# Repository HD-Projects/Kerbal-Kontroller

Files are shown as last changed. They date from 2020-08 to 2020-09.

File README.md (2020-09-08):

# Kerbal Kontroller




This is a external controller for the game Kerbal Space Program you need a [Artemis ATP](https://www.sparkfun.com/products/15442), [Artemis Module](https://www.sparkfun.com/products/15484), or any other board with 30+ digital pins.

# Table of Contents

* [Design](#design)
* [Software](#software)
* [Built it yourself](#Built-it-yourself)
* [Files](#File-system)

# Design

## Chosing which pins to include

After a little research on past designs for a kerbal controller we found that we wanted one that was bigger and used more high quality switches. After some frequency research(Playing KSP) we found that you pressed these buttons

* Throttle Up
* Cut Throttle
* Fine Throttle Control(Dial or Slide Potentiometer)
* Action groups
* WASD + Roll
* SAS Options
* Stage
* Quick Save
* Revert Buttons
* Manuver buttons
* Time Warp

We looked at this list and thought that it would be to many pins(~45) to implement on one arduino or RPi and we narrowed it down to this list

* Stage
* Throttle Dial
* WASD + Roll
* Action Groups(6)
* Internal Action groups
* SAS, RCS, Modable switch
* Quick Save, Revert save
* 4 Mod buttons

These buttons and switches took up about 25 pins so they could fit easly on one arduino so we moved on to designing the layout of the board. 

## Designing the layout

### First design

For our fist design we wanted to have a big board 30cm wide and 20cm tall, it was going to be huge! We kept adding on to this design and ended up with this design in this design we added 5 modable buttons for different buttons on the keyboard that the end user could change.

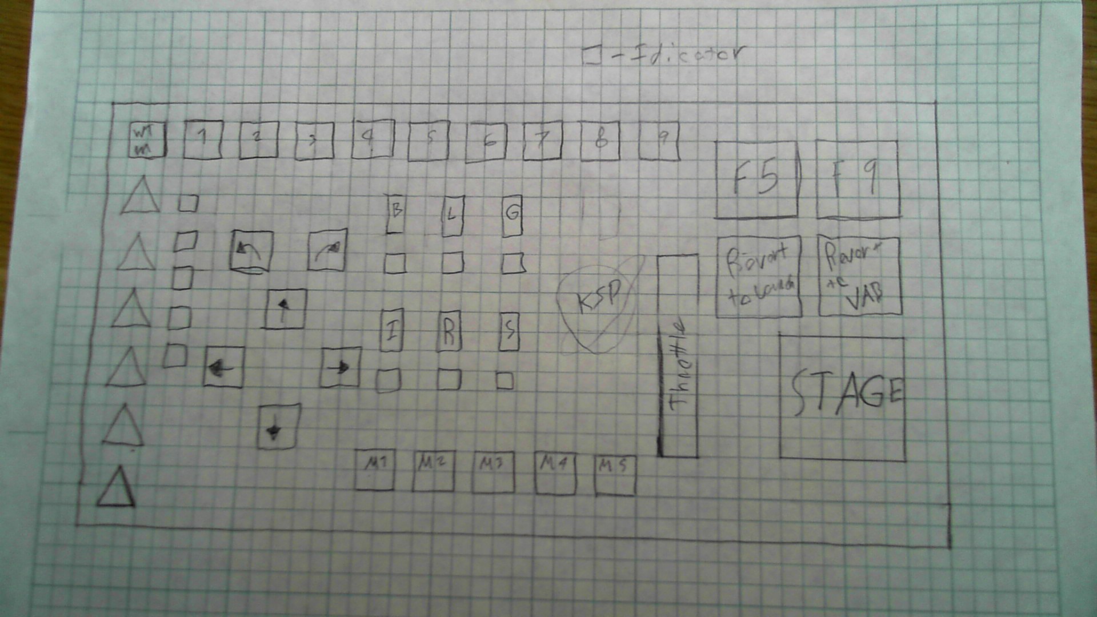
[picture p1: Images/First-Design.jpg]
First Design


We worked on thsi design for a while and created 2 prototypes in [this folder](Design/v.1) or [this folder](Design/v.2) We found that this design was going to be way too big and changed over to our much smaller second design 

### Second and Final Design

On our second design we got rid of the huge time warp selector, although helpful used up too many pins and could be a lot smaller. for this design we designed the layout of the buttons and switches then chose the size of the plexiglass we wanted

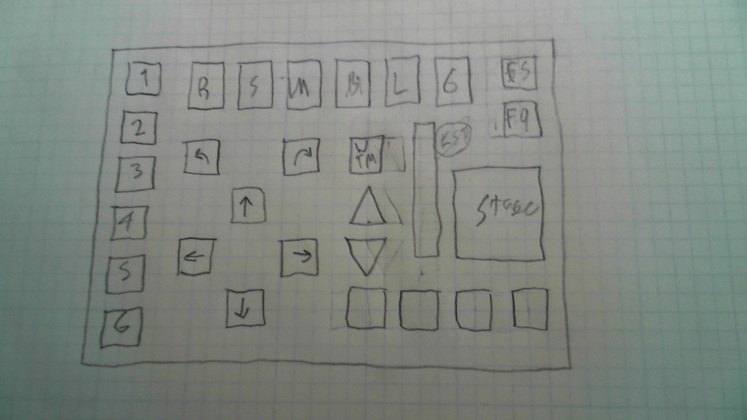
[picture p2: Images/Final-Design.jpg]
Final Design


This was a much smaller form factor and only have 22 buttons, 6 switches and one analog gauge, for a total of 28 digital pins, and only on analog pins. 

After we finnished the design we wanted to have a to scale model. we wanted some costomizablity for a flat design or a proped up design this is our first prototype of a proped up design

Front

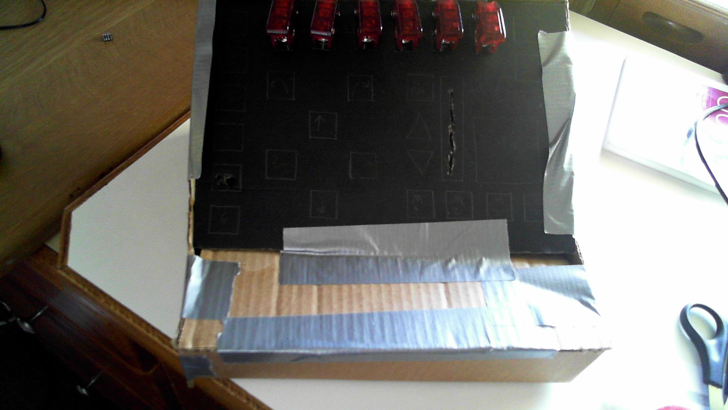
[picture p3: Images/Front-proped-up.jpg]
Proped up


Side

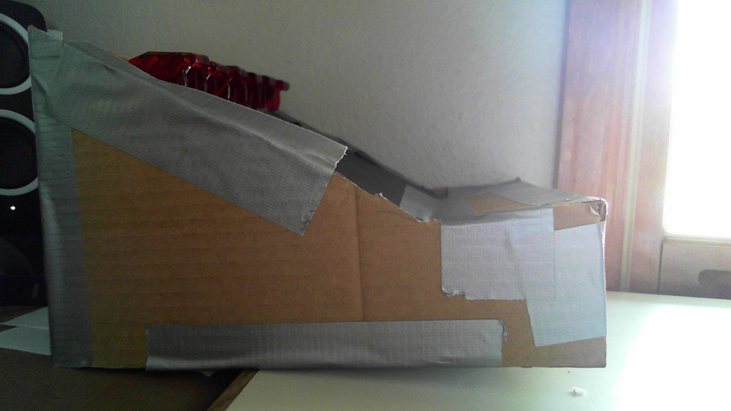
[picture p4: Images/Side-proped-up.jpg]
Proped up


Proped up

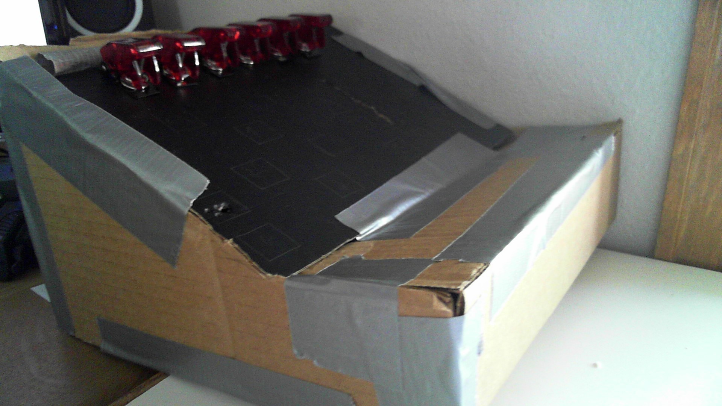
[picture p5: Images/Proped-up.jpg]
Proped up


We found that this would be the perfect size for our kerbal controller.

# Software

After doing some research on KSP mods for kerbal controllers we found this [post](https://www.reddit.com/r/KerbalControllers/comments/ajavos/software_comparison_thread/) on the different ways to do it can after looing at the pros and cons of each of them we thought that Kerbal Simpit would be the best for cosntomizablity and ease of use.

# Build-it-yourself

# Approach 1
Look at our [website](https://hdprojects.dev/ksp/diy)

# Approach 2

* First consult the parts list to buy all the parts

* Then get the faceplate cut and the keycaps 3d printed

* slot the keys+keycaps into ther respictive slots along with all the other parts

* use wire and solder all the parts into the right  i/o pins (digital pins for everything)

* download our code onto your aurdino

* profit?

# File-system

### CAD Section (design folder)

This is split into three parts 

* v.1
    * v.1 was our first design for our kerbal controller.
* v.2
    * v.2 was the same design just we totally redid the CAD Model to fix the many errors we had before.
* Final 
    * This is the only totally finnished design that would acctually work if you tried it.
   
### Glowforge (parts folder)

* glowforge folder (holds stl files)

* alternative folder (holds alternatives to using your own glowforge)

# 3d printing (in design folder) 
    
  * stl files
  
  * alternative folder (holds alternatives to using your own printer)

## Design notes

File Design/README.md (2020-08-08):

# design.md 

This folder holds all the cad files for the various iterations of the design, v1 is the initial release, v2 is the second release and "final" is the CAD files for the final design 
all the code files and parts are designed for the final version but we kept the last two in there if you want inspiration.

Look in the images folder for hot renders of the controller (so that those 41 hrs of cpu time aren't wasted).

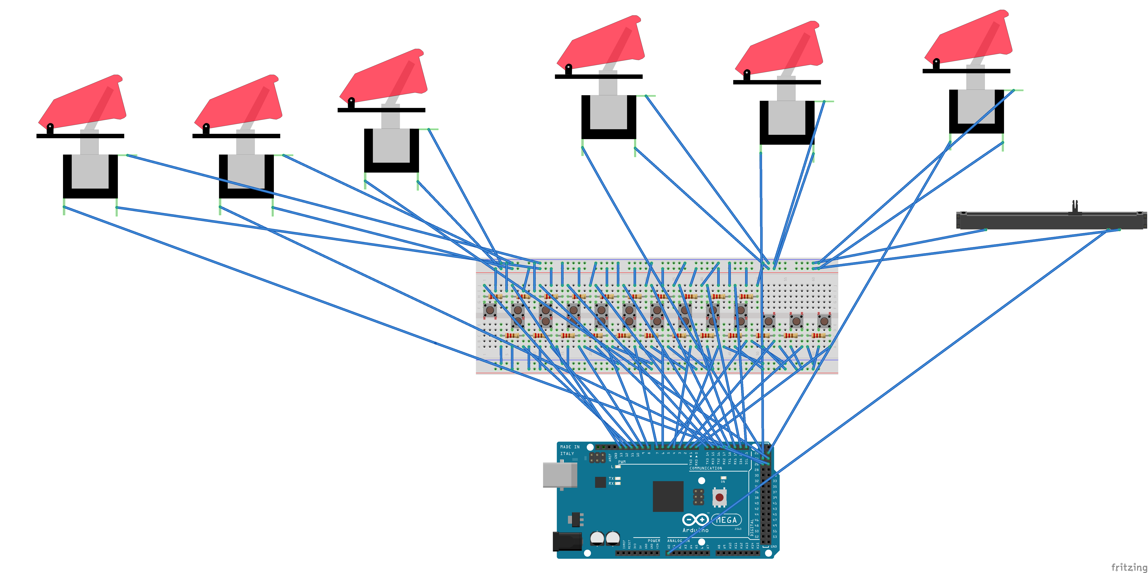
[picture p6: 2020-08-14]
Design/Final/Fritzing/Final_bb.png

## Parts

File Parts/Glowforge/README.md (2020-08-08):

# Glowforge

The 'final' folder  holds the info you need to use a glowforge or similar laser cutter to cut your controller parts. The SVG file is the file that will control the cut of the faceplate. If you would like to modify the faceplate open the SVG in a program such as Inkscape and edit it until satisfactory.

# Alternative 1

Use a laser cutting service that does the laser cutting for you

   Upload the SVG file from the "final" folder to a website such as https://www.ponoko.com/designs (our recommended laser cutting site) and select a material. Next proceed to    checkout and wait for your custom made faceplate to arrive. Note, do nout use a material such as steel or aluminum if you don't have a drill that can cut mounting holes in such a material.

# Alternative 2

Find a makerspace near you and get your item cut

   Open a website such as https://makerspaces.make.co/ to find a local makerspace near you. Then look at the makerspaces website (for our example https://members.10bitworks.com/) to see if they have a laser cutter capable of cutting your plexi. If they do follow the instructions for getting to use the equitpment and once you have secured a time to use the machine upload the svg from the final folder and proceed to get your faceplate cut/engraved.

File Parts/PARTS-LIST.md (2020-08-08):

# Parts list

## Table of Contents

* [3D Printing Files](#3D-Printing)
* [Electronic Parts](#Electronics)
* [Glowforge Files](#Glowforge)
* [Other Hardware](#Hardware)

## 3D-Printing

* [9 Keys(3d-printing option)](3d-Print/9-keys.stl) or buy 22 keycaps (18.57) from [3dhubs](https://www.3dhubs.com/) or (20.90) at [sparkfun](https://www.sparkfun.com/products/15305)

* [Stage](3d-Print/Stage.stl)  (8.80) from [3dhubs](https://www.3dhubs.com/)

## Electronics

* [Artemis Board W/ 28+ Digital Pins](https://www.sparkfun.com/search/results?term=artemis) (24.95)
* [22 Cherry MX keys](https://novelkeys.xyz/collections/switches/products/cherry-switches)  (21)
* [Slide Potentiometer](https://www.sparkfun.com/products/9119) & [Knob](https://www.sparkfun.com/products/9120) (2.95) + (0.95)
* [Toggle Switch and Cover](https://www.sparkfun.com/products/11310) (17.70)
* [Some Hookup Wire](https://www.sparkfun.com/products/8024) (2.50)
* [Resistors](https://www.sparkfun.com/products/14490) (0.95)

## Glowforge

* [Front Plexi](Glowforge/front-plexi.svg)

## Hardware

* [Plywood 1/4 in(1 Sheet)](https://www.homedepot.com/p/Sanded-Plywood-Common-15-32-in-x-2-ft-x-2-ft-Actual-0-451-in-x-23-75-in-x-23-75-in-300888/202093832) (7.98)
* [Plexiglass 1/16"](https://www.amazon.com/transparente-policarbonato-resistente-plexigl%C3%A1s-manualidades/dp/B07MQTDF4R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) (9.99)

Total Price

(18.57)keycaps + (8.80)stage btn + (24.95)aurdino + (21)keys + (2.95)slide pot + (0.95)slide pot knob + (17.70)toggle switch + (2.50)wire + (0.95)resistor + (7.98)plywood + (9.99)plexi = **115.89** for a completed controller

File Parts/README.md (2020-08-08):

# Parts

These are all the parts and files needed to complete the build.

# [PARTS-LIST.md](PARTS-LIST.md)

This is a file holding info on every part necessary to complete the build. It has links to buy components and links to the necessary files for the components you make yourself.

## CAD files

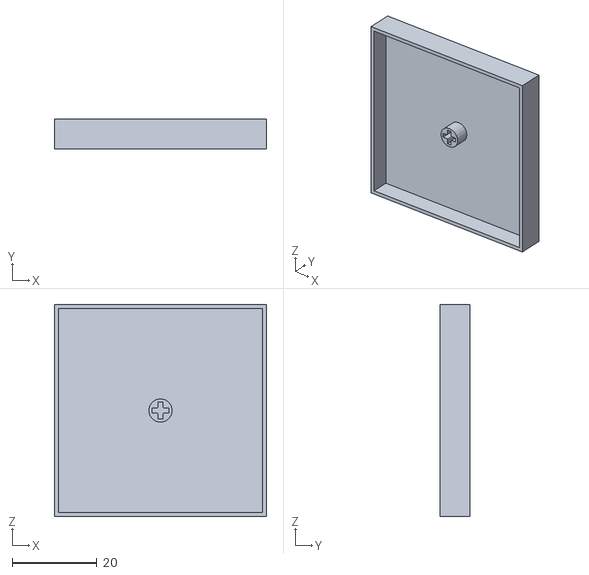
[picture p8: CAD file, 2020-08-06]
Design/Final/Inventor/Parts/Stage Keycap.obj
50.0 x 7.00 x 50.0

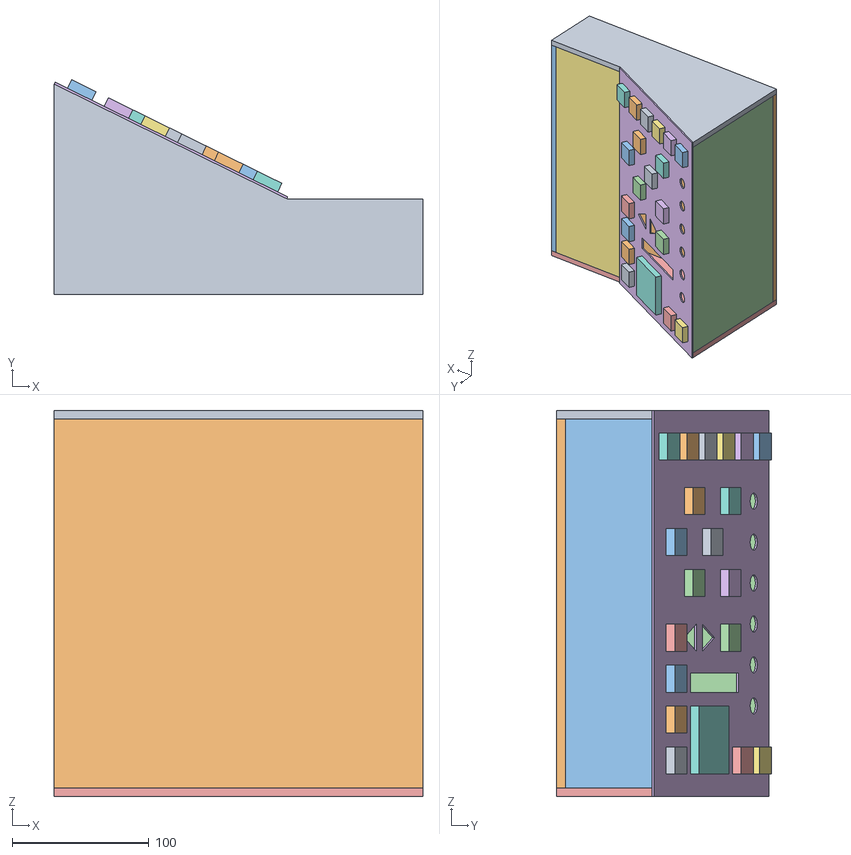
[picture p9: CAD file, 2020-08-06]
Design/Final/Object/Final.obj
270.0 x 157.3 x 282.7

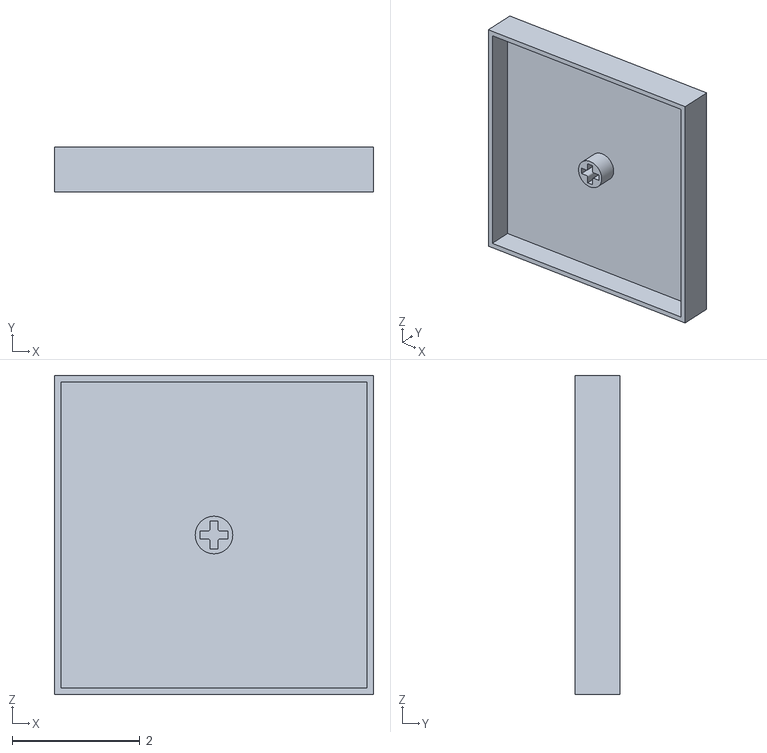
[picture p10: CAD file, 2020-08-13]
Parts/3d-Print/Stage.stl
5.00 x 0.7 x 5.00

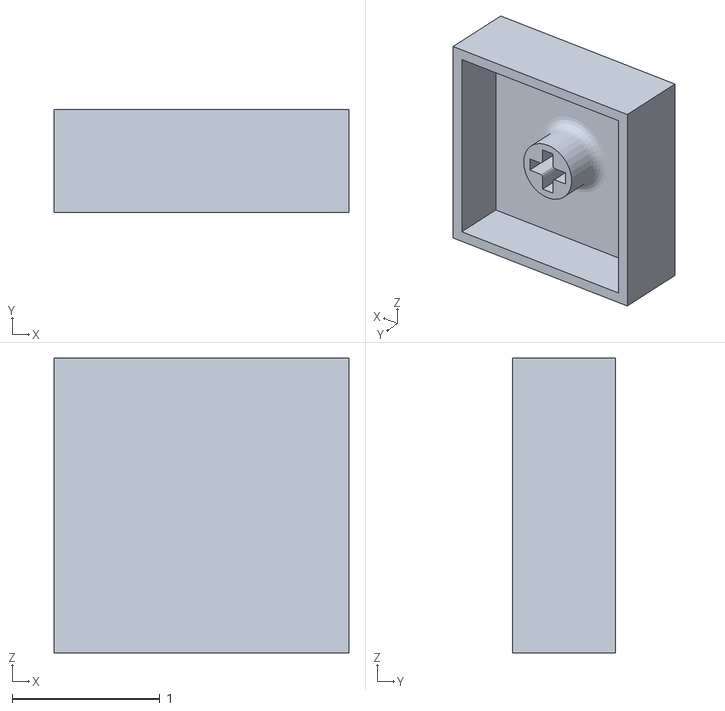
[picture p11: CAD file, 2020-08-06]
Parts/3d-Print/Keycap.stl
2.00 x 0.7 x 2.00

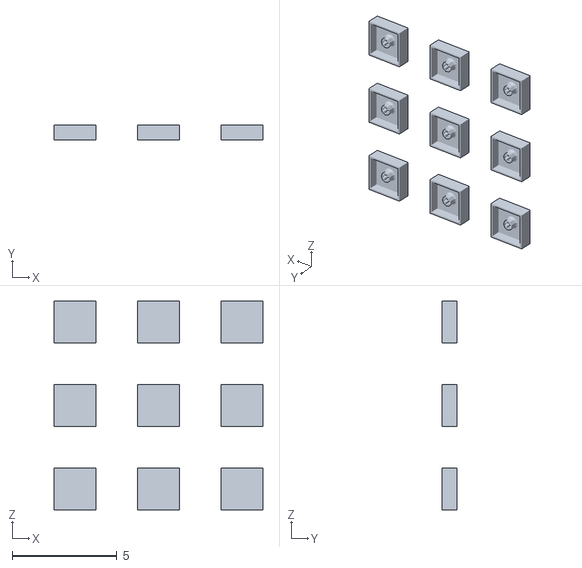
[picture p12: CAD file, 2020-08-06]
Parts/3d-Print/9-keys.stl
10.00 x 0.7 x 10.0

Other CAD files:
Design/Final/Step/Final.stp
Design/Final/Inventor/Final.iam
Design/Final/Inventor/OldVersions/Final.0010.iam
Design/Final/Inventor/OldVersions/Front Plywood.0001.ipt
Design/Final/Inventor/OldVersions/Front.0001.ipt
Design/Final/Inventor/OldVersions/v.3.0006.iam
Design/Final/Inventor/Parts/Arm Rest.ipt
Design/Final/Inventor/Parts/Back.ipt
Design/Final/Inventor/Parts/Bottom.ipt
Design/Final/Inventor/Parts/Front Plexi cutout.ipt
Design/Final/Inventor/Parts/Front.ipt
Design/Final/Inventor/Parts/Keycaps.ipt
Design/Final/Inventor/Parts/OldVersions/Arm Rest.0001.ipt
Design/Final/Inventor/Parts/OldVersions/Back.0002.ipt
Design/Final/Inventor/Parts/OldVersions/Bottom.0001.ipt
Design/Final/Inventor/Parts/OldVersions/Front Plexi cutout.0005.ipt
Design/Final/Inventor/Parts/OldVersions/Front Plywood.0004.ipt
Design/Final/Inventor/Parts/OldVersions/Front.0002.ipt
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

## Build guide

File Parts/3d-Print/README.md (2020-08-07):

# 3D-Printing Option

The 3d printing option prints all the keycaps on the board in squares. There are 2 STL Files you need to print the [Stage Button](Stage.stl) and the other [Keycaps](Keycap.stl) but we made a 100 mm x 100 mm [9 Keycap option](9-keys.stl)

# Alternative 1 

Use a custom 3d printing service

Use a website such as https://www.3dhubs.com/ https://www.shapeways.com/ https://i.materialise.com/en where you upload an stl file and get it printed and shipped to you. These parts will cost 10-15$ to make so you might consider using alternative 2 if you want to save money

# Alternative 2

find a makerspace near you and get your item printed

   Open a website such as https://makerspaces.make.co/ to find a local makerspace near you. Then look at the makerspaces website (for our example https://members.10bitworks.com/) to see if they have a 3d printer avaliabe for use. If they do follow the instructions for getting to use the equitpment and once you have secured a time to use the machine upload the stl from the 3d-print folder and proceed to get your parts printed.

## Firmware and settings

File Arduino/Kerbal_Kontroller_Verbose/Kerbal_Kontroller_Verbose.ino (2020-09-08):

// FILE: Kerbal_Kontroller_Verbose.ino

#include "KerbalSimpit.h"
#include "KerbalSimpitMessageTypes.h"
#include "PayloadStructs.h"

// Defining limits

//Dead Zone

#define DEADZONE 200

// Throttle

#define THROTTLE_HIGH -32768
#define THROTTLE_LOW 0

// Rotation Messages

#define ROTATION_HIGH 32767
#define ROTATION_LOW -32768

// Translation Messages

#define TRANSLATION_HIGH 32767
#define TRANSLATION_LOW -32768

// Kerbal Simpit rotation message

rotationMessage rotationMsg;

/*

Const switch setup we recomend the following
settings if you are following our directions

*/

// SAS + RCS + Mod

#define SAS_switch 6
#define RCS_switch 7 // The-Bit-One(Or u/hogthardwarf) will never have this switch on
#define mod_switch 8

// Built in Action Groups

#define lights_switch 9
#define brakes_switch 10
#define gear_switch 11

/*

Const for button pin, we reccomend the
following settings but feel free to change
it for your controller

*/

#define stage_button 2

// Controls

#define roll_right_button 12
#define roll_left_button 13
#define pitch_left_button 14
#define pitch_right_button 15
#define yaw_up_button 16
#define yaw_down_button 17

// Warp button

#define WTM_button 2 // Warp to manuver
#define warp_up_button 2
#define warp_down_button 2

// Quick Saves

#define quick_save_button 2
#define revert_quick_save_button 2


// Action Groups

#define action_1_button 0
#define action_2_button 1
#define action_3_button 2
#define action_4_button 3
#define action_5_button 4
#define action_6_button 5

// Mod Buttons

#define mod_1_button 18
#define mod_2_button 19
#define mod_3_button 20
#define mod_4_button 21

/*

Analog Pins

*/

// Throttle

#define throttle_gauge A5

// Done Setting Up Pins

KerbalSimpit mySimpit(Serial);

// My Simpit init

void simpitSetup(int pin) {
    Serial.begin(115200);

    digitalWrite(pin, HIGH);

    // This loop continually attempts to handshake with the plugin.
    // It will keep retrying until it gets a successful handshake.
    while (!mySimpit.init()) {
        delay(100);
    }
    // Turn off the built-in LED to indicate handshaking is complete.
    digitalWrite(pin, LOW);
}

void setup() {
    pinMode(LED_BUILTIN, OUTPUT);

    simpitSetup(LED_BUILTIN);

    // Start input setup

    // SAS + RCS + Mod

    pinMode(SAS_switch, INPUT);
    pinMode(RCS_switch, INPUT);
    pinMode(mod_switch, INPUT);

    // Built-in Action groups

    pinMode(lights_switch, INPUT);
    pinMode(brakes_switch, INPUT);
    pinMode(gear_switch, INPUT);

    // Stage

    pinMode(stage_button, INPUT);

    // Controls

    pinMode(roll_right_button, INPUT);
    pinMode(roll_left_button, INPUT);
    pinMode(pitch_left_button, INPUT);
    pinMode(pitch_right_button, INPUT);
    pinMode(yaw_up_button, INPUT);
    pinMode(yaw_down_button, INPUT);

    // Warp Buttons

    pinMode(WTM_button, INPUT);
    pinMode(warp_up_button, INPUT);
    pinMode(warp_down_button, INPUT);

    // Quick Saves

    pinMode(quick_save_button, INPUT);
    pinMode(revert_quick_save_button, INPUT);

    // Action Groups

    pinMode(action_1_button, INPUT);
    pinMode(action_2_button, INPUT);
    pinMode(action_3_button, INPUT);
    pinMode(action_4_button, INPUT);
    pinMode(action_5_button, INPUT);
    pinMode(action_6_button, INPUT);
}

void loop() {
    mySimpit.update();

    // Debounce

    // Stage
    if(digitalRead(stage_button) == HIGH){
        // Delay 50 for hardware Debounce

        delay(50);
        
        if(digitalRead(stage_button) == LOW){
            // Button Press Counted

            mySimpit.activateAction(STAGE_ACTION);
        }
    }

    // IDK if Kerbal Simpit supports Warping yet

    if(digitalRead(WTM_button) == HIGH){
        // Delay 50 for hardware Debounce

        delay(50);
        
        if(digitalRead(WTM_button) == LOW){
            // Button Press Counted

            // IDK
        }
    } 

    // Time warp up

    if(digitalRead(warp_up_button) == HIGH){
        // Delay 50 for hardware Debounce

        delay(50);
        
        if(digitalRead(warp_up_button) == LOW){
            // Button Press Counted

            // press(".")  no timewarp on Artemis ATP
        }
    } 

    // Time warp down

    if(digitalRead(warp_down_button) == HIGH){
        // Delay 50 for hardware Debounce

        delay(50);
        
        if(digitalRead(warp_down_button) == LOW){
            // Button Press Counted

            // press(",")  no timewarp on Artemis ATP
        }
    } 

    // Press button to quick save

    if(digitalRead(quick_save_button) == HIGH){
        // Delay 50 for hardware Debounce

        delay(50);
        
        if(digitalRead(quick_save_button) == LOW){
            // Button Press Counted

            // press(F5)  no timewarp on Artemis ATP
        }
    }

    // Press button to revert

    if(digitalRead(revert_quick_save_button) == HIGH){
        // Delay 50 for hardware Debounce

        delay(50);
        
        if(digitalRead(revert_quick_save_button) == LOW){
            // Button Press Counted

            // press(F9) & hold no timewarp on Artemis ATP
        }
    }

    // Action group 1

    if(digitalRead(action_1_button) == HIGH){
        // Delay 50 for hardware Debounce

        delay(50);
        
        if(digitalRead(action_1_button) == LOW){
            // Button Press Counted

            mySimpit.toggleCAG(1);
        }
    }

    // Action group 2

    if(digitalRead(action_2_button) == HIGH){
        // Delay 50 for hardware Debounce

        delay(50);
        
        if(digitalRead(action_2_button) == LOW){
            // Button Press Counted

            mySimpit.toggleCAG(2);
        }
    }

    // Action group 3

    if(digitalRead(action_3_button) == HIGH){
        // Delay 50 for hardware Debounce

        delay(50);
        
        if(digitalRead(action_3_button) == LOW){
            // Button Press Counted

            mySimpit.toggleCAG(3);
        }
    }

    // Action group 4

    if(digitalRead(action_4_button) == HIGH){
        // Delay 50 for hardware Debounce

        delay(50);
        
        if(digitalRead(action_4_button) == LOW){
            // Button Press Counted

            mySimpit.toggleCAG(4);
        }
    }

    // Action group 5

    if(digitalRead(action_5_button) == HIGH){
        // Delay 50 for hardware Debounce

        delay(50);
        
        if(digitalRead(action_5_button) == LOW){
            // Button Press Counted

            mySimpit.toggleCAG(5);
        }
    }

    // Action group 6

    if(digitalRead(action_6_button) == HIGH){
        // Delay 50 for hardware Debounce

        delay(50);
        
        if(digitalRead(action_6_button) == LOW){
            // Button Press Counted

            mySimpit.toggleCAG(6);
        }
    }

    /* 

    Mod buttons

    The mod buttons have 2 choices debounce or constaint
    like the control buttons the below code is the debounce
    put a close tag below, customize the action and brake the close tag
    
    

    // Mod 1

    if(digitalRead(mod_1_button) == HIGH){
        // Delay 50 for hardware Debounce

        delay(50);
        
        if(digitalRead(mod_1_button) == LOW){
            // Button Press Counted

            // Your Action
        }
    }

    // Mod 1

    if(digitalRead(mod_2_button) == HIGH){
        // Delay 50 for hardware Debounce

        delay(50);
        
        if(digitalRead(mod_2_button) == LOW){
            // Button Press Counted

            // Your Action
        }
    }

    // Mod 3

    if(digitalRead(mod_3_button) == HIGH){
        // Delay 50 for hardware Debounce

        delay(50);
        
        if(digitalRead(mod_3_button) == LOW){
            // Button Press Counted

            // Your Action
        }
    }

    // Mod 1

    if(digitalRead(mod_4_button) == HIGH){
        // Delay 50 for hardware Debounce

        delay(50);
        
        if(digitalRead(mod_4_button) == LOW){
            // Button Press Counted

            // Your Action
        }
    }

    */

    /*

    Second option

    Press down for cuntinuous action

    

    // Mod 1

    if(digitalRead(mod_1_button)){
        // Your Action
    }

    // Mod 2

    if(digitalRead(mod_2_button)){
        // Your Action
    }

    // Mod 3

    if(digitalRead(mod_3_button)){
        // Your Action
    }

    // Mod 4

    if(digitalRead(mod_4_button)){
        // Your Action
    }

    */

    // Set up rotation masking to know what to send

    rotationMsg.mask = 1|2|4;

    // Set roll

    if(digitalRead(roll_right_button)){
        // Set rotaion message roll
        rotationMsg.roll = 32767;
    }
    if(digitalRead(roll_left_button)){
        // Set rotaion message roll
        rotationMsg.roll = -32768;
    }

    // Set pitch

    if(digitalRead(pitch_left_button)){
        // Set rotaion message pitch
        rotationMsg.pitch = 32767;
    }
    if(digitalRead(pitch_right_button)){
        // Set rotaion message pitch
        rotationMsg.pitch = -32768;
    }

    // Set yaw

    if(digitalRead(yaw_up_button)){
        // Set rotaion message yaw
        rotationMsg.pitch = 32767;
    }
    if(digitalRead(yaw_down_button)){
        // Set rotaion message yaw
        rotationMsg.pitch = -32768;
    }

    // Send rotationMsg to the Kerbal Simpit plugin
    mySimpit.send(ROTATION_MESSAGE, rotationMsg);

    int brakesDigitalRead = digitalRead(gear_switch); // 1 Getting status of brakes switch we are using an integer variable but only two values are 
    // possible "HIGH" meaning true or activate and and "LOW" meaning false
    int lightDigitialRead = digitalRead(lights_switch); // 2
    int gearDigitalRead = digitalRead(gear_switch); // 3
    int sasDigitalRead = digitalRead(SAS_switch); // 4
    int rcsDigitalRead = digitalRead(RCS_switch); // 5
    int modDigitalRead = digitalRead(mod_switch); // 6

    if (brakesDigitalRead == HIGH /* high is this case is erqual to a boolean 'true' */) {
        mySimpit.deactivateAction(BRAKES_ACTION); // deavtivating brakes
    }
    else /* checking if button is not active or "LOW" */ {
        mySimpit.activateAction(BRAKES_ACTION);  // activating brakes
    }
    if (lightDigitialRead == HIGH /* high is this case is erqual to a boolean 'true' */) {
        mySimpit.deactivateAction(LIGHT_ACTION); // deavtivating brakes
    }
    else /* checking if button is not active or "LOW" */ {
        mySimpit.activateAction(LIGHT_ACTION);  // activating brakes
    }
    if (gearDigitalRead == HIGH /* high is this case is erqual to a boolean 'true' */) {
        mySimpit.deactivateAction(GEAR_ACTION); // deavtivating brakes
    }
    else /* checking if button is not active or "LOW" */ {
        mySimpit.activateAction(GEAR_ACTION);  // activating brakes
    }

    if (sasDigitalRead == HIGH /* high is this case is erqual to a boolean 'true' */) {
        mySimpit.deactivateAction(SAS_ACTION); // deavtivating brakes
    }
    else /* checking if button is not active or "LOW" */ {
        mySimpit.activateAction(SAS_ACTION);  // activating brakes
    }

    if (rcsDigitalRead == HIGH /* high is this case is erqual to a boolean 'true' */) {
        mySimpit.deactivateAction(RCS_ACTION); // deavtivating brakes
    }
    else /* checking if button is not active or "LOW" */ {
        mySimpit.activateAction(RCS_ACTION);  // activating brakes
    }

    //!!!!!!!!!!!!!!!!
    // IMPORTANT
    // Please insert your desired action in the /* Your action */ comment

    if (mod_switch == HIGH /* high is this case is erqual to a boolean 'true' */) {
        mySimpit.deactivateAction(ABORT_ACTION/* Your action */); //deavtivating brakes
    } else /* checking if button is not active or "LOW" */ {
        mySimpit.activateAction(ABORT_ACTION/* Your action */);  //activating brakes
    }
    //IMPORTANT
    //!!!!!!!!!!!!!

    // keypress emulation syntax   Keyboard.press(ctrlKey); Keyboard.press('n');
}

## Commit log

2020-08-04 Inital Commit
    [Arm Rest.ipt, Back.ipt, Backplane.ipt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]
2020-08-06 Added 3d Pintable parts
    [3x3 Keycaps, 10x10 cm.stl, Stage Keycap.obj]
2020-08-06 Added parts list and updated CAD models
    [9-keys.stl, Back.0001.ipt, Back.ipt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]
2020-08-06 update Plexi
    [Front Plexi cutout.0004.ipt, Front Plexi cutout.0005.ipt, Front Plexi cutout.ipt]
2020-08-07 Added Pin Setup
2020-08-07 Finnished Pin Setup
2020-08-07 moved the ino file, getting ready for prototypes
2020-08-10 Working on refining the design Next I will update the CAD model.
    [Stage Keycap.0001.ipt, Stage Keycap.ipt, Stage.stl]
2020-08-10 working on CAD design Made plywood wider and added textures
    [All Keys.0001.iam, All Keys.iam, Arm Rest.0001.ipt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]
2020-08-10 working on rendering
    [Final.0009.iam, Final.0010.iam, Final.iam]
2020-08-11 working on the arduino Code - i think i got debounce solved
    [Kerbal_Kontroller.ino]
2020-08-13 Y wont commits work
    [Stage.stl]
2020-08-13 update SVG file
    [Final.fzz]
2020-08-14 Fix Throttle
2020-08-18 I think I finnished up the arduino Code
2020-08-18 We need keyboard emulation https://www.reddit.com/r/arduino/comments/icc1r4/arduino_keyboard_library_for_non_32u4_or_samd/
2020-08-19 Building arduino code
2020-08-19 Take away the key emulation buttons
2020-09-06 😟Messed up on plexiglass
2020-09-08 🚀Added Kerbal! And also fixed the plexiglass
    [Kerbal_Kontroller_Verbose.ino]
2020-09-08 👨‍💻A+ Code according to Codefactor.io
